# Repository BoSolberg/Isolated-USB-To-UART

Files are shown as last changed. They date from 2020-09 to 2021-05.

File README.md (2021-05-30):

# Isolated-USB-To-UART
### A Simple 5kV Isolated USB To UART Bridge

The isolated USB to UART Bridge works with Baudrates from 300 baud to 3 Mbaud.</br>
It can withstand 5000Vrms for 1 minute.</br>
And 565Vpeak Continuously, without destroying your computer.</br>

It can opperate with a circuit voltage from 1.8V to 5V.

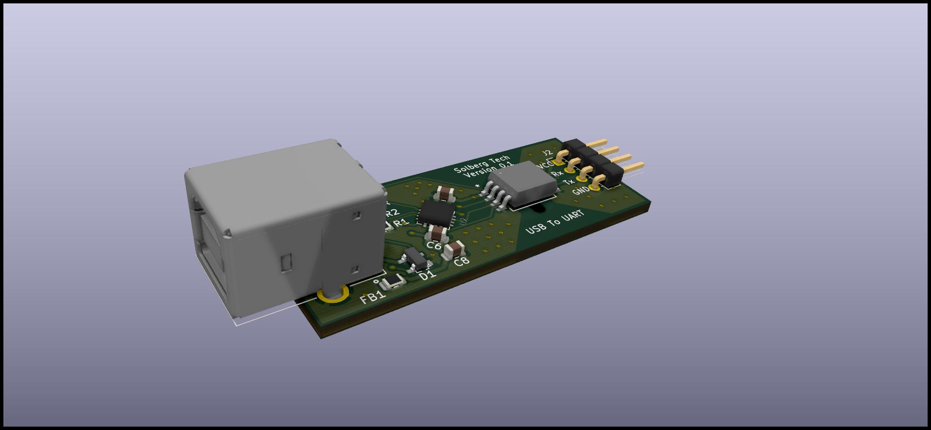
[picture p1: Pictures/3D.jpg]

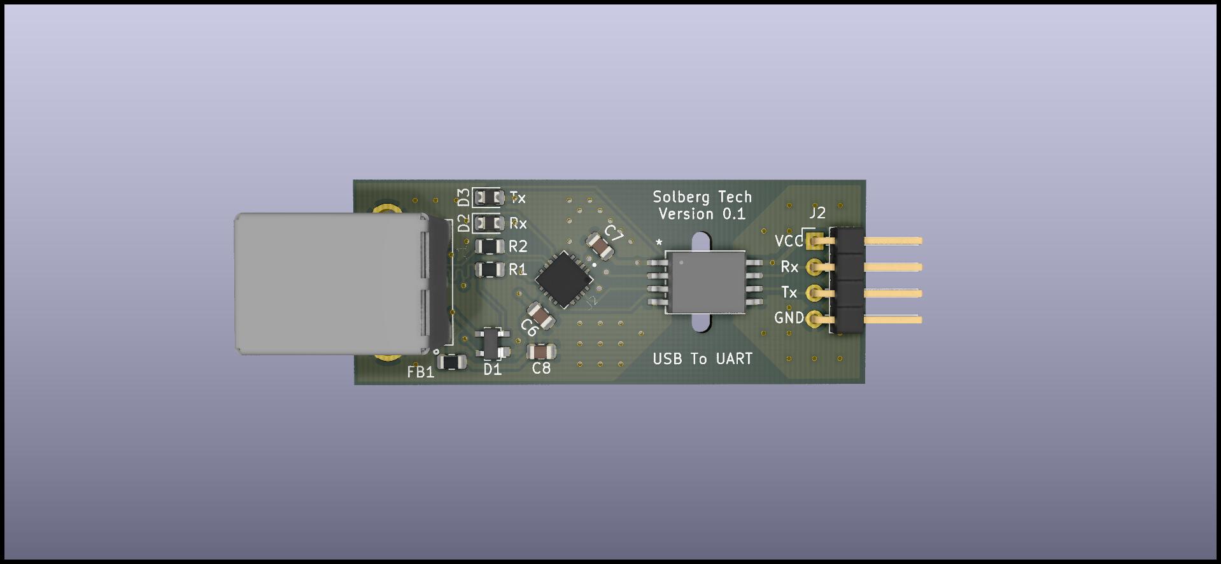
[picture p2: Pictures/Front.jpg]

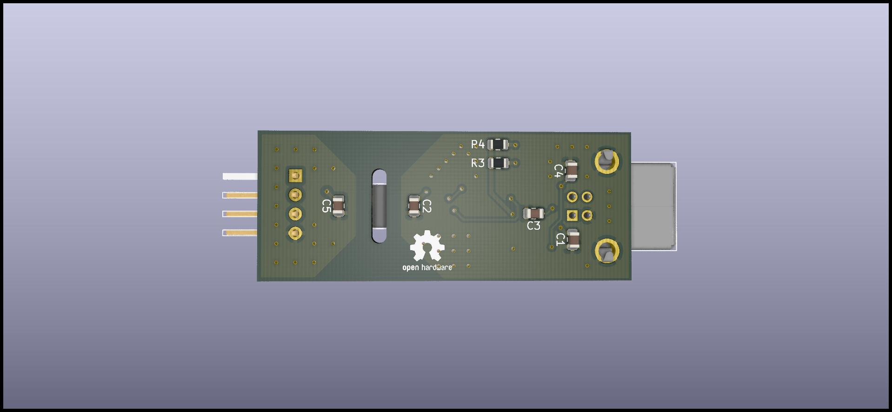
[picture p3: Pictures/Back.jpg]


<p xmlns:dct="http://purl.org/dc/terms/" xmlns:cc="http://creativecommons.org/ns#" class="license-text">This work   is licensed under <a rel="license" href="https://creativecommons.org/licenses/by-sa/4.0">CC BY-SA 4.0</a></p>

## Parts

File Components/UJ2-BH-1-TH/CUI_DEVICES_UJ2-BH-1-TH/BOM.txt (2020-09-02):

3DX_CUI_DEVICES_Supplier: CUI Devices
3DX_CUI_DEVICES_Description: 3 µin Plating Thickness, Black Insulator, USB Receptacle
3DX_CUI_DEVICES_Model Number: UJ2-BH-1-TH

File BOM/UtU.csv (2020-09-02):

Source: | C:\Users\bosol\Documents\KiCAD\Tindie\USB to UART\UtU\UtU.sch
Date: | 01-09-2020 15:56:24
Tool: | Eeschema (5.1.6)-1
Generator: | C:\Program Files\KiCad\bin\scripting\plugins/bom_csv_grouped_by_value.py
Component Count: | 20
Collated Components:
Item | Qty | Designator | Description / Value | Digi-Key_PN | Mfg Part # | Manufacturer
1 | 1 | C1 | CAP CER 10000PF 16V X7R 0805 | 311-3161-1-ND | AC0805KRX7R7BB103 | Yageo
2 | 2 | C2, C5 | CAP CER 0.022UF 16V X7R 0805 | 311-3163-1-ND | AC0805KRX7R7BB223 | Yageo
3 | 2 | C3, C4 | CAP CER 47PF 50V C0G/NPO 0805 | 311-1107-1-ND | CC0805JRNPO9BN470 | Yageo
4 | 2 | C6, C7 | CAP CER 0.1UF 16V X7R 0805 | 311-1142-1-ND | CC0805KRX7R7BB104 | Yageo
5 | 1 | C8 | CAP CER 4.7UF 16V X5R 0805 | 311-1867-1-ND | CC0805KKX5R7BB475 | Yageo
6 | 1 | D1 | TVS DIODE 5.5V 8.5V SOT143-4 | F2715CT-ND | SP0503BAHTG | Littelfuse Inc.
7 | 1 | D2 | LED GREEN DIFFUSED 0805 SMD | 475-1410-1-ND | LG R971-KN-1 | OSRAM Opto Semiconductors Inc.
8 | 1 | D3 | LED RED DIFFUSED 0805 SMD | 475-1415-1-ND | LH R974-LP-1 | OSRAM Opto Semiconductors Inc.
9 | 1 | FB1 | FERRITE BEAD 600 OHM 0805 | 240-2390-1-ND | MI0805K601R-10 | Laird-Signal Integrity Products
10 | 1 | J1 | CONN RCPT USB2.0 TYPEB 4POS R/A | 102-3999-ND | UJ2-BH-1-TH | CUI Devices
11 | 1 | J2 | CONN HEADER R/A 4POS 2.54MM | 2057-PH1RB-04-UA-ND | PH1RB-04-UA | Adam Tech
12 | 2 | R1, R2 | RES SMD 27 OHM 1% 1/8W 0805 | 311-27.0CRCT-ND | RC0805FR-0727RL | Yageo
13 | 1 | R3 | RES SMD 560 OHM 5% 1/8W 0805 | 311-560ARCT-ND | RC0805JR-07560RL | Yageo
14 | 1 | R4 | RES SMD 680 OHM 5% 1/8W 0805 | 311-680ARCT-ND | RC0805JR-07680RL | Yageo
15 | 1 | U1 | DGTL ISO 5000VRMS 2CH GP 8SOIC | ADUM226N0BRIZ-ND | ADUM226N0BRIZ | Analog Devices Inc.
16 | 1 | U2 | IC USB SERIAL BASIC UART 16QFN | 768-1130-1-ND | FT230XQ-R | FTDI, Future Technology Devices International Ltd

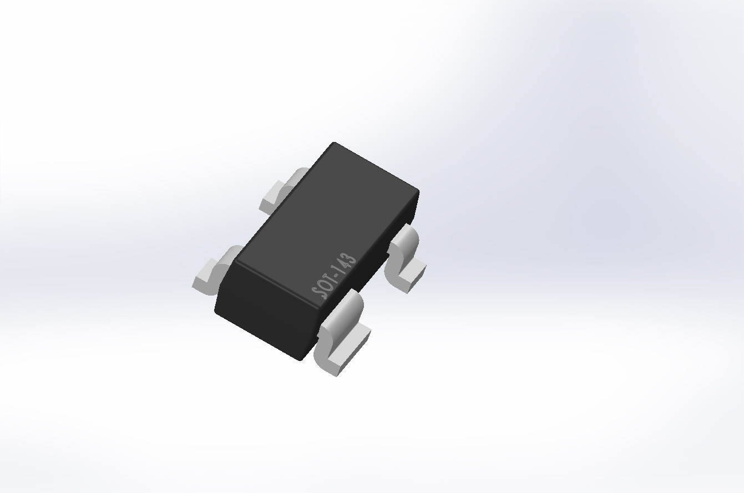
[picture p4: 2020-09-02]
Components/sot-143-1.snapshot.1/Assem1.JPG

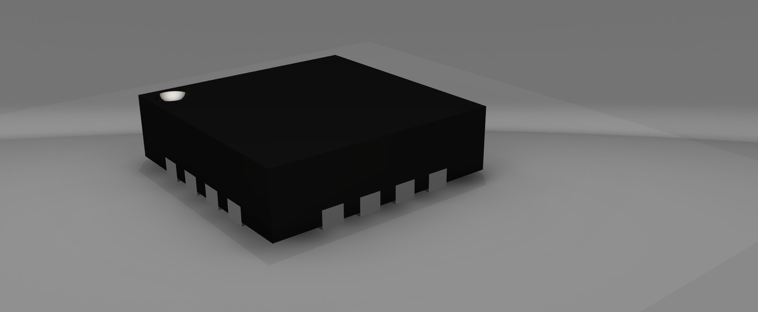
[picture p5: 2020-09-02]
Components/FT230XQ-R/qfn-16-1.snapshot.2/QFN-16 (3x3).png

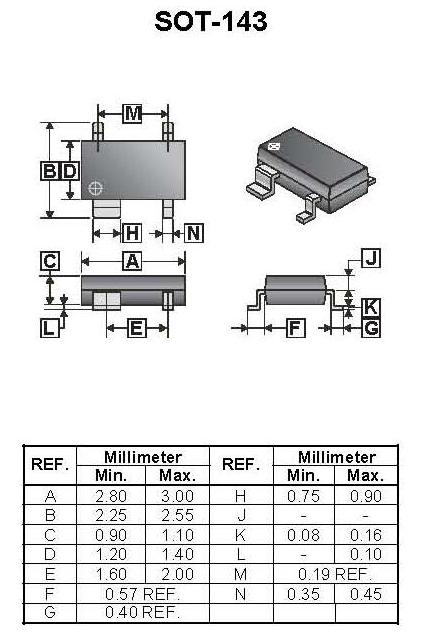
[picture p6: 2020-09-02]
Components/sot-143-1.snapshot.1/SOT-143.jpg

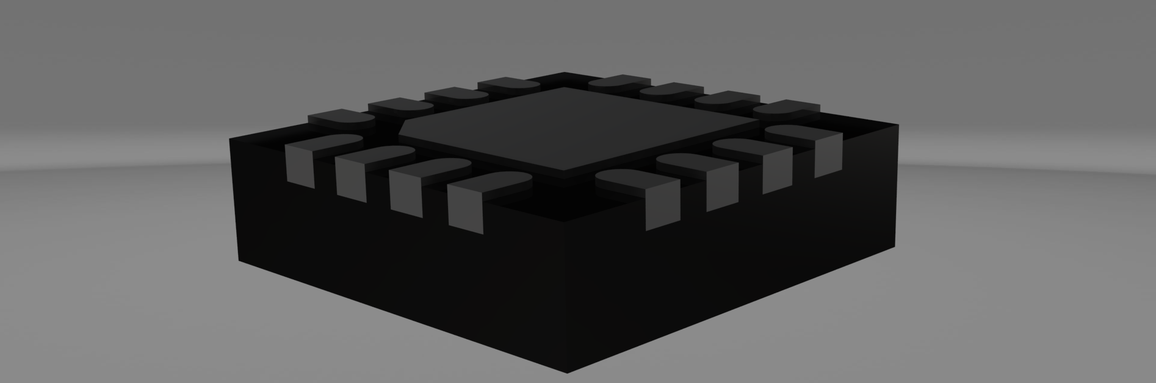
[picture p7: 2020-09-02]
Components/FT230XQ-R/qfn-16-1.snapshot.2/QFN-16 (3x3)2.png

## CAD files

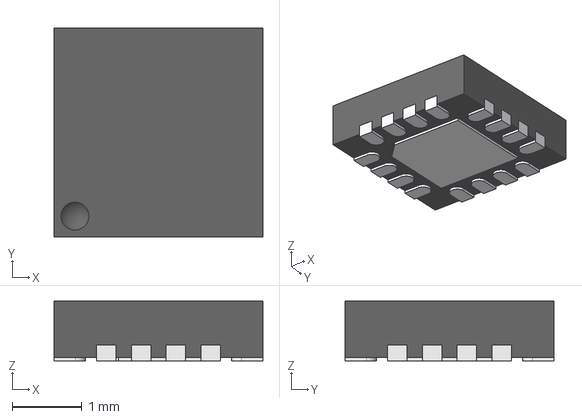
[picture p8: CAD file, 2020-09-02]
Components/FT230XQ-R/qfn-16-1.snapshot.2/QFN-16 (3x3).stp
3.00 x 3.00 x 0.86 mm
QFN-16 (3x3) Part1
QFN-16 (3x3) Part2 x 16

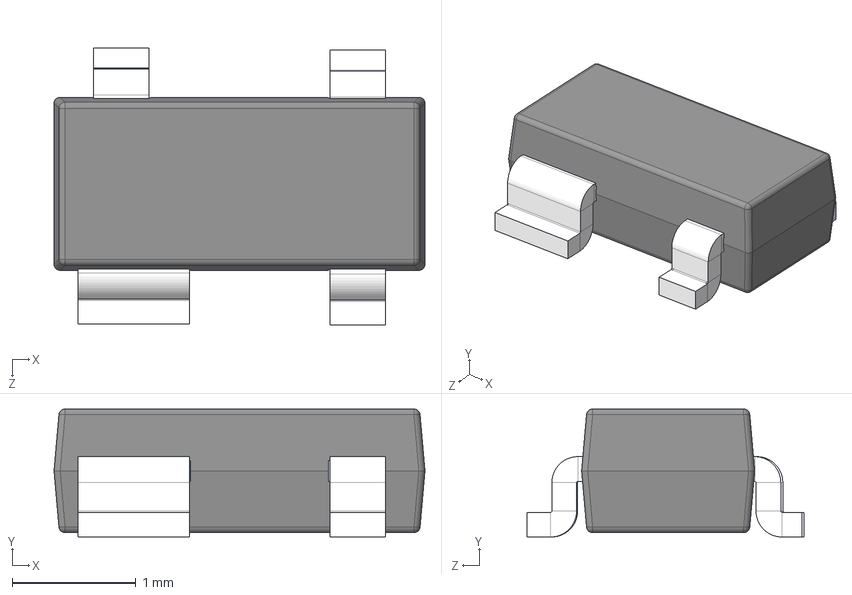
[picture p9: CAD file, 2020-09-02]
Components/sot-143-1.snapshot.1/Assem1.STEP
3.00 x 1.04 x 2.24 mm

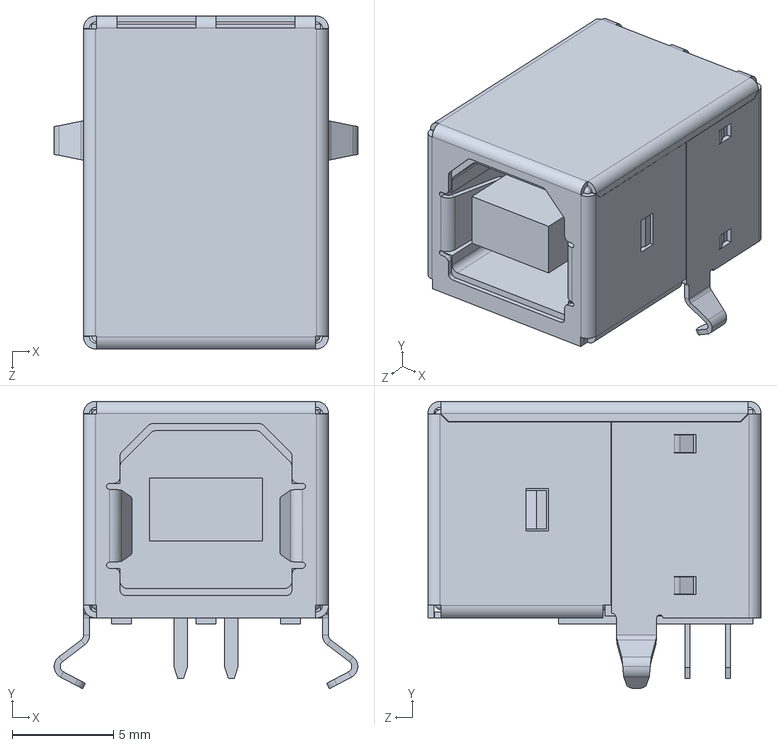
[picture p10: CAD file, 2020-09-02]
Components/UJ2-BH-1-TH/CUI_DEVICES_UJ2-BH-1-TH/CUI_DEVICES_UJ2-BH-1-TH.step
15.0 x 14.2 x 16.5 mm

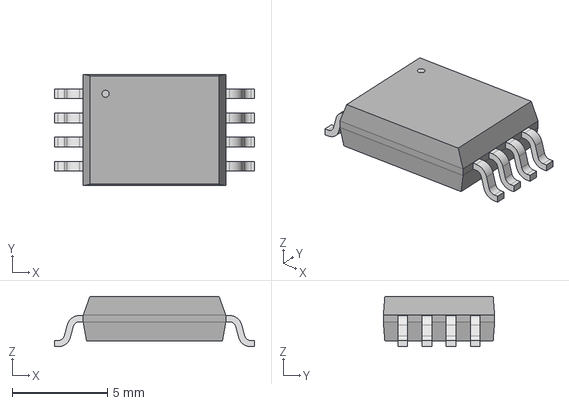
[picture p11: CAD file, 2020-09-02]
Components/ul_ADUM226N0BRIZ/2020-08-31_19-36-18/STEP/RI_8_1_ADI-M.step
10.5 x 5.85 x 2.65 mm

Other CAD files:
Components/ul_ADUM226N0BRIZ/2020-08-31_19-36-18/STEP/RI_8_1_ADI-L.step
Components/ul_ADUM226N0BRIZ/2020-08-31_19-36-18/STEP/RI_8_1_ADI.step
Components/FT230XQ-R/qfn-16-1.snapshot.2/QFN-16 (3x3) Assembly.prt
Components/FT230XQ-R/qfn-16-1.snapshot.2/QFN-16 (3x3) Part1.prt
Components/FT230XQ-R/qfn-16-1.snapshot.2/QFN-16 (3x3) Part2.prt
Components/sot-143-1.snapshot.1/Assem1.SLDASM

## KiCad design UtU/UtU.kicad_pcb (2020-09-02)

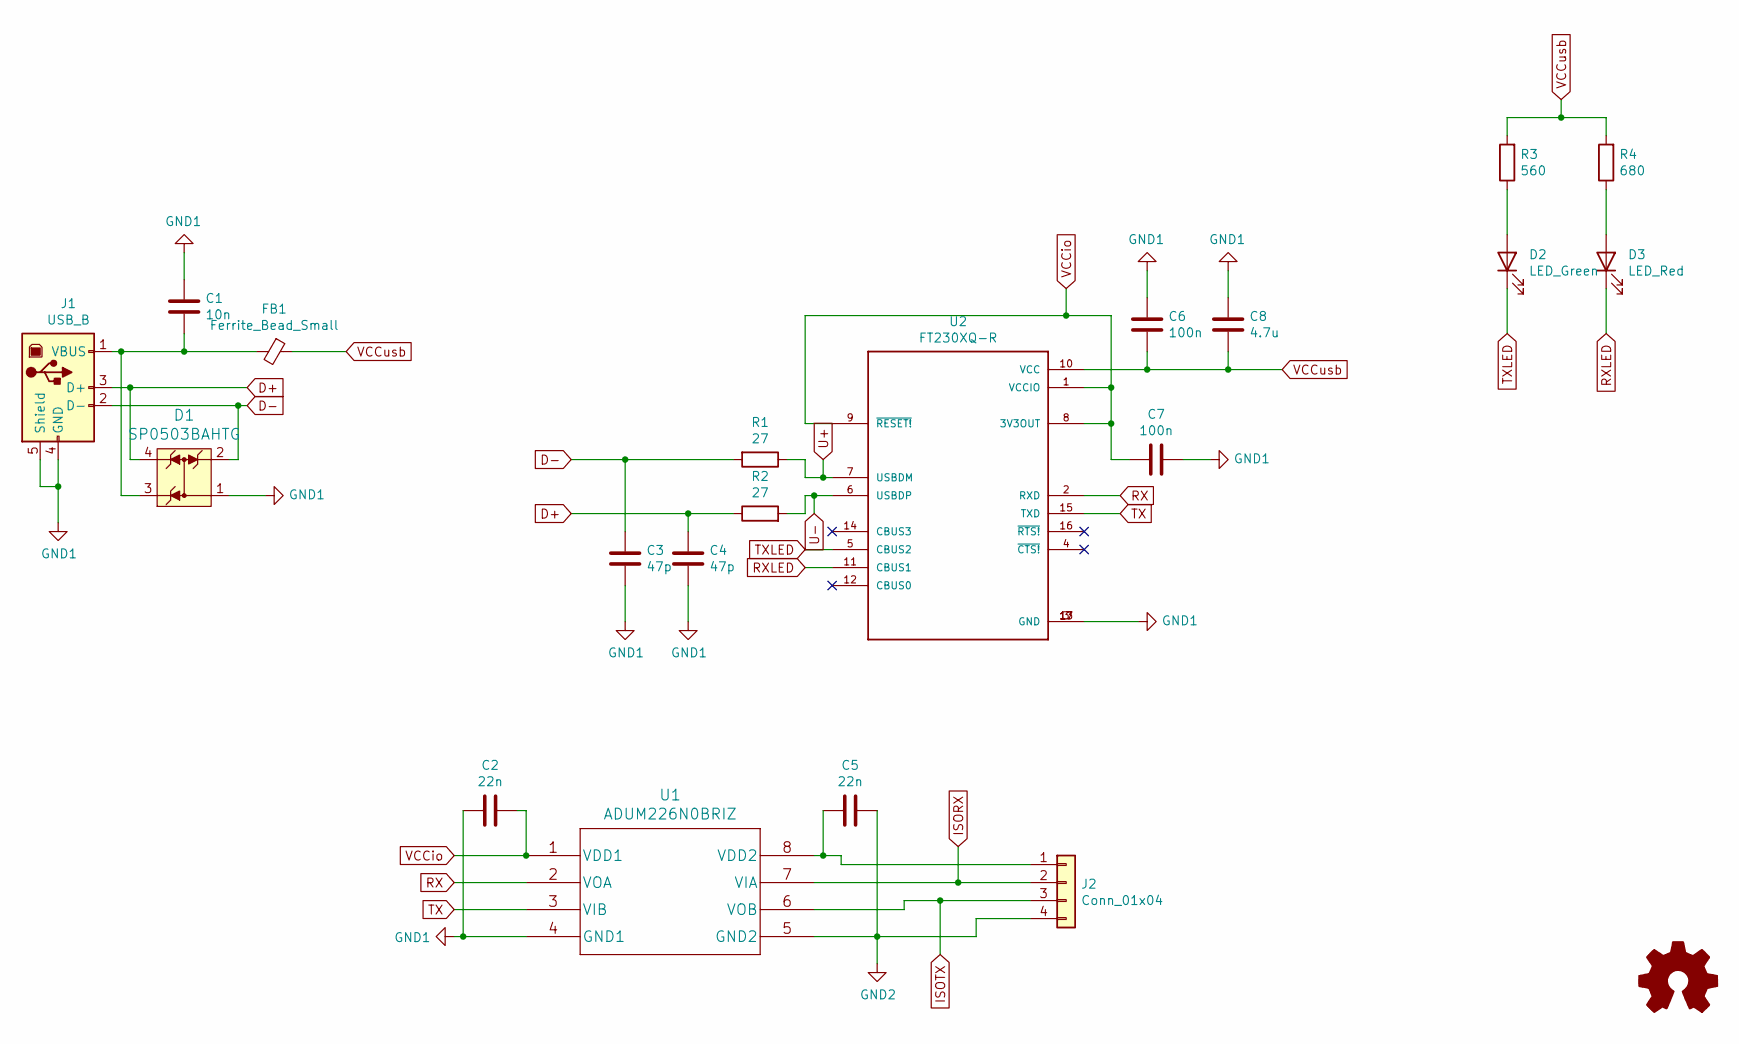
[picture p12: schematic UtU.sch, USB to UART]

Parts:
C1: 10n; C_0805_2012Metric; MPN AC0805KRX7R7BB103; Digi-Key_PN 311-3161-1-ND
C2, C5: 22n; C_0805_2012Metric; MPN AC0805KRX7R7BB223; Digi-Key_PN 311-3163-1-ND
C3, C4: 47p; C_0805_2012Metric; MPN CC0805JRNPO9BN470; Digi-Key_PN 311-1107-1-ND
C6, C7: 100n; C_0805_2012Metric; MPN CC0805KRX7R7BB104; Digi-Key_PN 311-1142-1-ND
C8: 4.7u; C_0805_2012Metric; MPN CC0805KKX5R7BB475; Digi-Key_PN 311-1867-1-ND
D1: SP0503BAHTG; SOT-143-4; MPN SP0503BAHTG; Digi-Key_PN F2715CT-ND
D2: LED_Green; D_0805_2012Metric; MPN LG R971-KN-1; Digi-Key_PN 475-1410-1-ND
D3: LED_Red; D_0805_2012Metric; MPN LH R974-LP-1; Digi-Key_PN 475-1415-1-ND
FB1: Ferrite_Bead_Small; R_0805_2012Metric; MPN MI0805K601R-10; Digi-Key_PN 240-2390-1-ND
J1: USB_B; CUI_UJ2-BH-1-TH; MPN UJ2-BH-1-TH; Digi-Key_PN 102-3999-ND
J2: Conn_01x04; PinHeader_1x04_P2.54mm_Horizontal; MPN PH1RB-04-UA; Digi-Key_PN 2057-PH1RB-04-UA-ND
R1, R2: 27; R_0805_2012Metric; MPN RC0805FR-0727RL; Digi-Key_PN 311-27.0CRCT-ND
R3: 560; R_0805_2012Metric; MPN RC0805JR-07560RL; Digi-Key_PN 311-560ARCT-ND
R4: 680; R_0805_2012Metric; MPN RC0805JR-07680RL; Digi-Key_PN 311-680ARCT-ND
U1: ADUM226N0BRIZ; MPN ADUM226N0BRIZ; Digi-Key_PN ADUM226N0BRIZ-ND
U2: FT230XQ-R; QFN65P400X400X80-17N; MPN FT230XQ-R; Digi-Key_PN 768-1130-1-ND

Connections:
D+: C4.1, D1.4, J1.3 (D+), R2.1
D-: C3.1, D1.2, J1.2 (D-), R1.2
GND1: C1.1, C2.2, C3.2, C4.2, C6.1, C7.2, C8.1, D1.1, J1.4 (GND), J1.5 (Shield), U1.4 (GND1), U2.3 (GND), U2.13 (GND), U2.17 (GND)
GND2: C5.1, J2.4, U1.5 (GND2)
ISORX: J2.2, U1.7 (VIA)
ISOTX: J2.3, U1.6 (VOB)
unnamed: C1.2, D1.3, FB1.2, J1.1 (VBUS)
unnamed: C5.2, J2.1, U1.8 (VDD2)
unnamed: D2.2 (A), R3.1
unnamed: D3.2 (A), R4.1
RX: U1.2 (VOA), U2.2 (RXD)
RXLED: D3.1 (K), U2.11 (CBUS1)
TX: U1.3 (VIB), U2.15 (TXD)
TXLED: D2.1 (K), U2.5 (CBUS2)
U+: R1.1, U2.7 (USBDM)
U-: R2.2, U2.6 (USBDP)
VCCio: C2.1, C7.1, U1.1 (VDD1), U2.1 (VCCIO), U2.8 (3V3OUT), U2.9 (~RESET!~)
VCCusb: C6.2, C8.2, FB1.1, R3.2, R4.2, U2.10 (VCC)

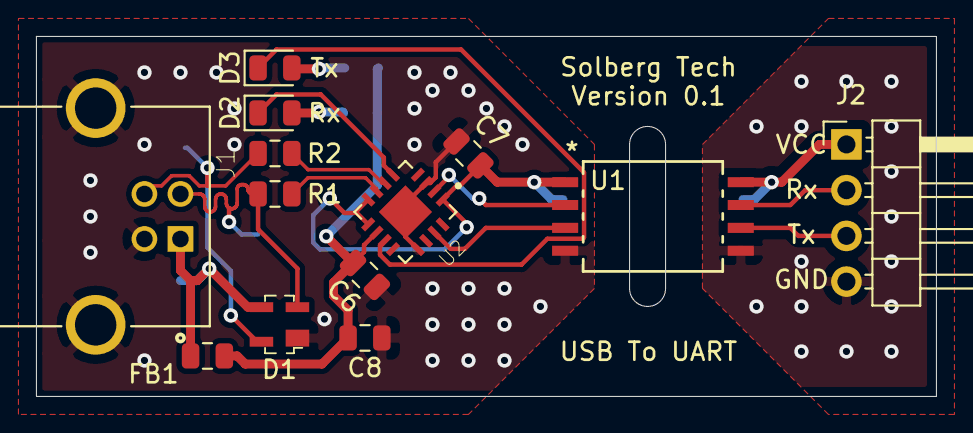
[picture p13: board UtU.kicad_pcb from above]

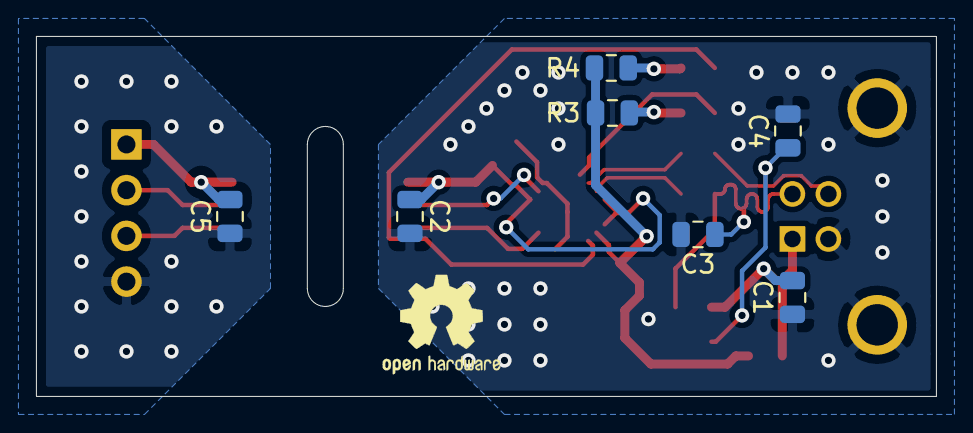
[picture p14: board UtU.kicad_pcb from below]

Board: 2 copper layers, 50.0 x 20.0 mm, 20 parts (7 on the bottom side), 18 nets.

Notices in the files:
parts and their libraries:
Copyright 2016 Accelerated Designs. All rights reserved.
